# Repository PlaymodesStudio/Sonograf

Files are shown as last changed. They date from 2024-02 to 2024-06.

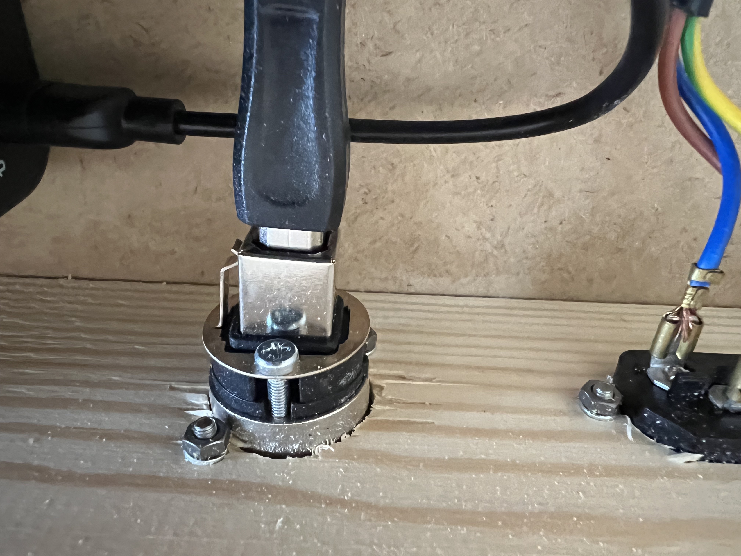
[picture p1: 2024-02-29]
PHOTOS/USB_wiring.jpg

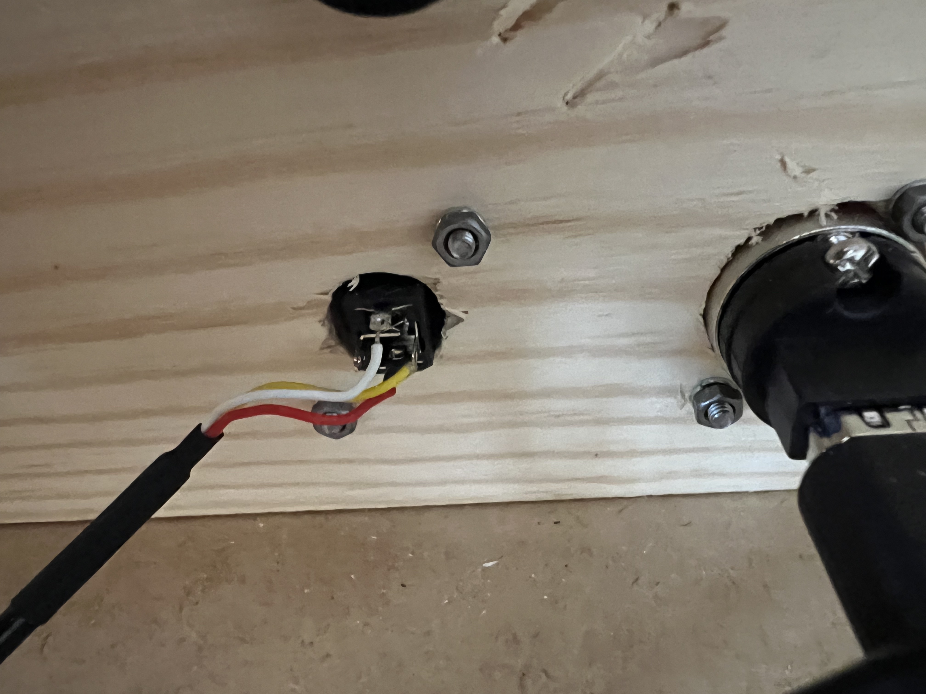
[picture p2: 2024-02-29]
PHOTOS/minijack_wiring.jpg

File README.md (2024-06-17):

SONÒGRAF DIY MATERIALS
https://www.playmodes.com/home/sonograf/

Sonògraf © 2022 by Playmodes Studio is licensed under Attribution-NonCommercial-ShareAlike 4.0 International 

final_setup

This is a compilation of software, materials list, 3d print files, CNC designs and instructions for you to build your own Sonògraf.

Please be aware that the software (a Raspberry PI 4 image file) is complete and fully working, as this constitutes the fundamental element of the Sonògraf instrument.
The source codes for the software components are provided, if you feel brave enough to analyze, make sense of the package and make your custom modifications.

Please find the software elements of the Sonògraf, including a release featuring a ready-to-burn Raspberry Pi .img file here: https://github.com/PlaymodesStudio/Sonograf_Software

(please note that we provide 2 different images: a shrinked one, hosted in github, and a complete one, hosted in Dropbox. Some people has had errors with the shrinked image, so we recommend to go directly to the full .img with the dropbox link)

The 3D prints and CNC files are provided as a mere starting point for your own project, and shouldn’t be taken as fabrication-ready:

-Some of the material listed elements can be discontinued (specific products out of stock or not being fabricated anymore)

-The 3D printing and CNC files are provided in a variety of formats (svg, ai, stl…) and you must carefully check that the designs match your materials.

-Some assembly images can give you a reference on how we did it. But, again, this can be useful or not depending on your specific design and materials availability.

-You will need some level of understanding on basic electronics (ie: wire a knob or button to an rpi adc), and be patient enough to guess how to put everything together at the hardware and software level.

-Some extra designs are provided: logotypes, pieces for collage composition…

-As of June 2024, Filippo Centenari (https://www.filippocentenari.it/) has graciously contributed with a step-by-step assembly guide. It is a very well documented PDF with all the needed stepes to follow for the set-up of a Sonògraf. Thank you Filippo!

-A user manual and educational guide is also provided, in spanish and catalan. Sorry, no english translation yet! (If you want to contribute with an English translation of the educational guide, or with a new one with your own experience, in english, this will be a highly appreciated contribution!)

Although we can’t provide personal support or guidance for possible problems with this package, we always welcome feedback and we are eager to know if you succesfully built your own version of the Sonògraf.

Please let us know your experience at info@playmodes.com

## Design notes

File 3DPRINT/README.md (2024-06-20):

3DPRINT FOLDER
Files Description

LED_Support.stl
a 3d printer ready file, with the design of the brackets that hold the LED bar

Paper_6mm_support.stl
a 3d printer ready file, with the design of the brackets that hold the A4 paper

Webcam_base.stl
a 3d printer ready file, with the design of the base to be fixed to the inner part of the wood case cover

Webcam_joint.stl
a 3d printer ready file, with the design of the joint to be fixed directly to the webcam

Webcam_support.stl
a 3d printer ready file, with the design of the support to be placed between the base and the joint

Hinge.stl
The hinge design to hold the cover of the box

Icon-set.stl
The set of icons for the physical controls, just in case you preffer to glue 3d prints instead of laser engraving these

neutrik-jack.stl
A cover for the neutrik jack connector

USB-B Neutrik-inner-support.stl
A cover for the USB connector

LOGO v1.stl
A 3D print version of the logotype, if you preffer 3D print instead of CNC

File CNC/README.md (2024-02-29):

CNC FOLDER
Files Description

Board_cut.ai
a CNC design for cutting a plywood board, adapted to the size and needs of the case listed on the materials list. It includes holes for the buttons and knobs.
If you are using a different case, buttons, or knobs, this design might not be valid for you.
In any case, please carefully check the dimensions before printing!

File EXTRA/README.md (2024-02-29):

EXTRA FOLDER
Files Description

Logotype_cut.svg
The needed pieces to put together the sonograf logotype at the cover of the case

pieces_cut.ai
Some designs for pre-made tokens which can be used as elements of a composition when playing with the Sonògraf

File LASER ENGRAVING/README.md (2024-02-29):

LASER ENGRAVING FOLDER
Files Description

board_engraving.svg
Icons and marks to be engraved on the board. This design should match the board cut pattern in the cnc folder, but please review carefully before proceeding.

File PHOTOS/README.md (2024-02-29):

PHOTOS FOLDER
Files Description

board_hole.jpg
A detail on how the side hole on the CNCed board is used to make the camera and LED bar cables pass by towards the inner side of the instrument

board.jpg
A view of the fully assembled board

board_rear.jpg
A view of the board on its rear part, with the buttons and knobs wired to the adc shield of the RPI4

button_wiring.jpg
A detail on the button wiring on the rear side of the board

camera_base.jpg
A detail of the camera base, screwed to the cover

camera_joint.jpg
A detail of the camera joint, assembled to the other parts

camera_match.jpg
A detail of the matching parts of the camera support

camera_support.jpg
A detail of the whole camera 3d printed support, in standby position

case_cover.jpg
A detail of the case cover. Pay attention to the screws that fix the camera base and the CNCed logotype.

case_hinge.jpg
A detail of the case 3d printed hinge

diagram.png
A diagram showing all the visible parts of the instrument

final_setup.jpg
A final setup example, with speakers and videoprojector

general_view_inner.jpg
A view of the inner part of the instrument, showing the RPI4 and the different wiring and power elements

general_view.jpg
A general view of the visible parts of the instrument once assembled

HDMI.jpg
A detail of the HDMI connector on the inner side

IEC_wiring.jpg
A detail of the IEC connector, on the inner side.

inner_view.jpg
A view of the inner part of the instrument, showing the RPI4 and the different wiring and power elements

knob_wiring.jpg
A detail on the button wiring on the rear side of the board

latch1.jpg
A detail on the latch parts screwed to the case

latch2.jpg
A detail on the latch parts screwed to the case

LED_support.jpg
A detail of the 3d printed LED support

minijack_wiring.jpg
A detail of the minijack connector, on the inner side.

RPI_adc.jpg
A detail view of the ADC shield for the RPI4

rpi_connections.jpg
A detail view of the different connections to the RPI conenctors. Please note that the ethernet connection/wire is not needed

USB_wiring.jpg
A detail of the USB connector, on the inner side.

using_pieces.jpg
An example image of the sonograf being used with the CNC pieces for collage compositions

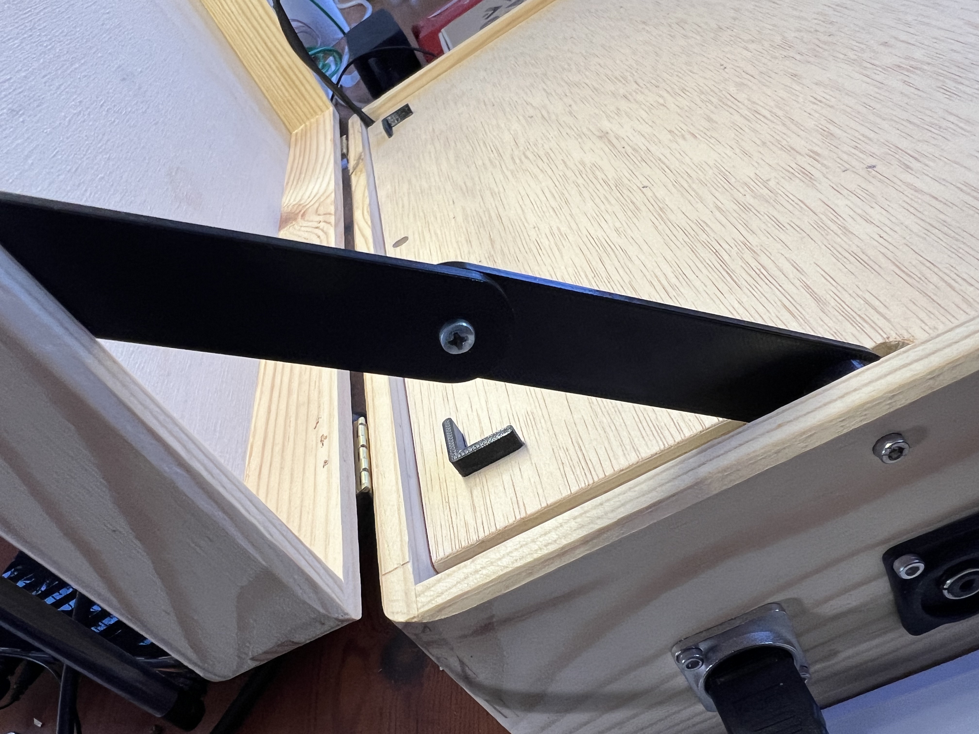
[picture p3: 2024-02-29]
PHOTOS/case_hinge.jpg

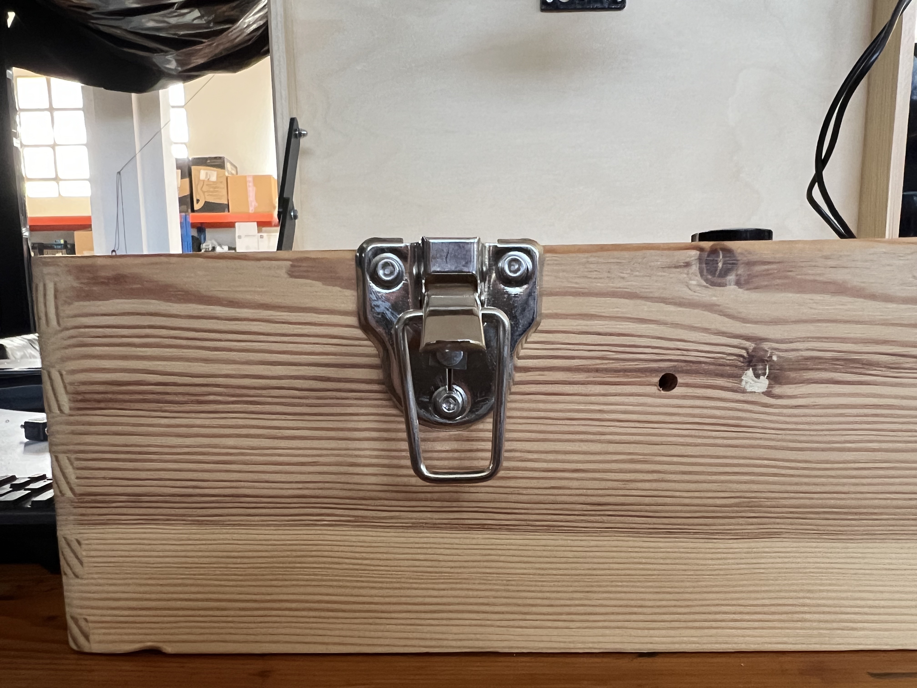
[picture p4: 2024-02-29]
PHOTOS/latch2.jpg

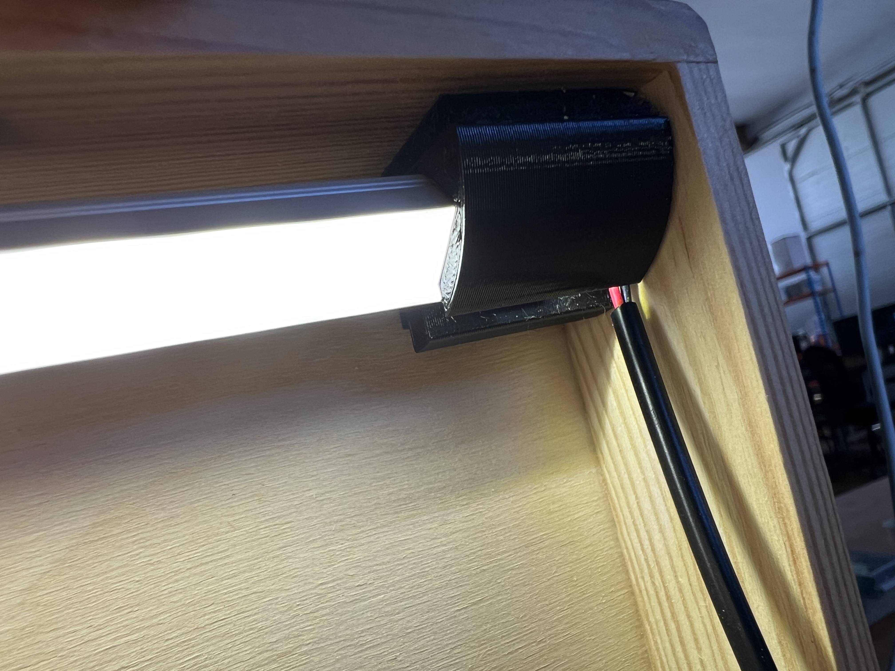
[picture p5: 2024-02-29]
PHOTOS/LED_support.jpg

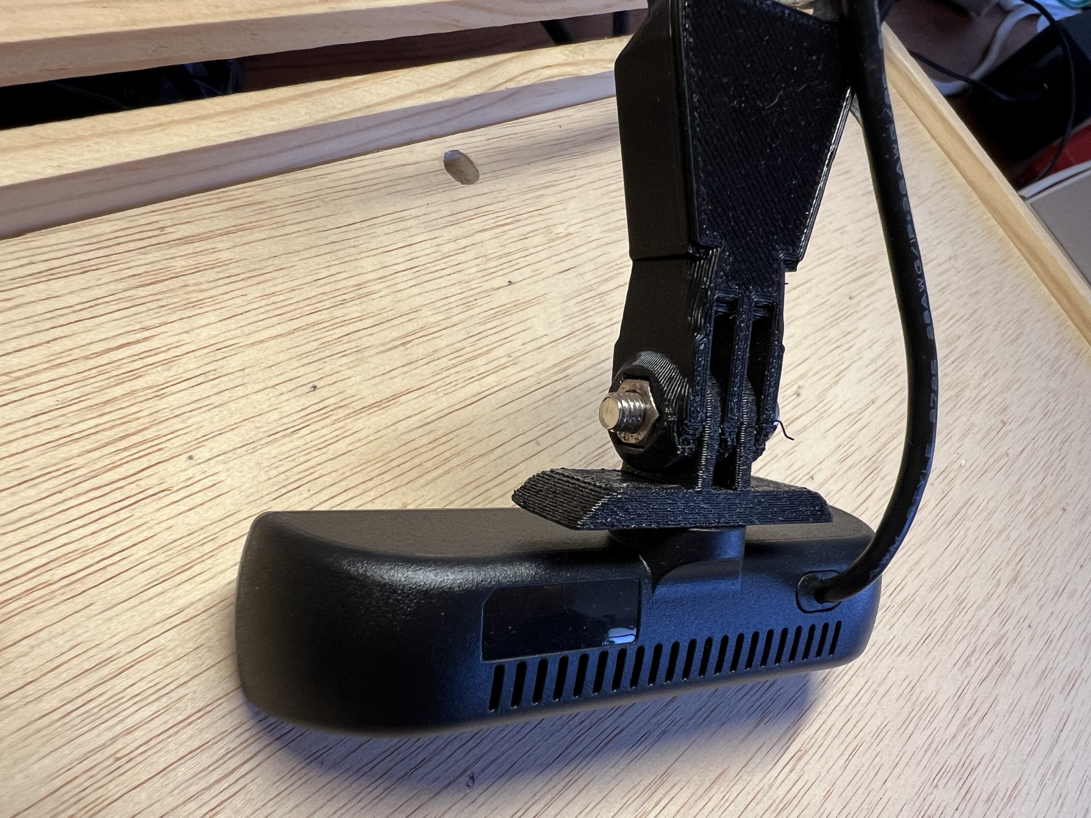
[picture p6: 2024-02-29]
PHOTOS/camera_joint.jpg

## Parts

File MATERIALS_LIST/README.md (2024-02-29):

SONÒGRAF MATERIALS LIST

On this list you will find the needed materials for a full assembly of the Sonògraf, together with its approximate price and a reference link to the material.

Please be aware that some of the materials on this list can be discontinued or out of stock, the links broken, etc.

You can probably work with other replacement parts, or make a full redesign of the Sonògraf hardware while just keeping the software.

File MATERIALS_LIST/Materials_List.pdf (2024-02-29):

Units | Unit Price (€) | Subtotal (€)
Kit RaspberryPI 4 (RPI + SD + HDMI) | 1 | 100,00 € | 100,00 € | https://www.kubii.com/en/nano-computers/3011-starter-kit-raspberry-pi4-4gb-3272496302112.html Multi power plug with USB | 1 | 14,00 € | 14,00 € | https://www.amazon.es/JSVER-pararrayos-Protectores-sobretensiones-Smartphone/dp/B07JMVSJHV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
Neutrik USB female connector | 1 | 7,14 € | 7,14 € | https://www.amazon.es/gp/product/B003L79T06/ref=ppx_yo_dt_b_asin_title_o01_s00?ie=UTF8&psc=1
Neutrik HDMI female connector | 2 | 8,00 € | 16,00 € | https://www.amazon.es/Neutrik-NAHDMI-W-Conector-Plata-25-85/dp/B004E88DMG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
USB soundcard for RPI4 | 1 | 6,50 € | 6,50 € | https://www.amazon.es/gp/product/B07S4LJ28C/ref=ppx_yo_dt_b_asin_title_o07_s00?ie=UTF8&psc=1
Aukey fullHD USB Webcam | 1 | 32,00 € | 32,00 € | https://www.pccomponentes.com/aukey-webcam-fullhd-usb
IEC Connector | 1 | 1,00 € | 1,00 € | https://www.tme.eu/es/details/cs-033/conectores-iec-60320/
IEC soldering terminals | 3 | 0,10 € | 0,30 € | https://www.tme.eu/es/details/2670.05.00.9/conectores-no-aislados/imp/
Potentiometers 10kohm | 4 | 2,00 € | 8,00 € | https://www.tme.eu/es/details/r16148-1a-2-b10k/potenciometros-de-carbono-de-una-revol/sr-passives/
Potentiometer Caps | 4 | 3,00 € | 12,00 € | https://www.tme.eu/es/details/gf6m-25x15-c/perillas-para-potenciometros-axiales/sr-passives/
25cm minijack wire | 1 | 2,24 € | 2,24 € | https://cablematic.com/es/productos/cable-audio-stereo-minijack-35-mm-20cm-TV077/?cr=EUR&ct=ES Minijack Female connector | 1 | 3,65 € | 3,65 € | https://www.amazon.es/gp/product/B073QW1RB2/ref=ppx_yo_dt_b_asin_title_o00_s00?ie=UTF8&psc=1
USB wire 25cm | 1 | 0,75 € | 0,75 € | https://cablematic.com/ca/productes/cable-usb-20-ab-mascle-blanc-20cm-UR031/
LED bar | 1 | 8,36 € | 8,36 € | https://www.amazon.es/gp/product/B08GLRYYX2/ref=ppx_yo_dt_b_asin_title_o05_s00?ie=UTF8&psc=1
Placa rpi amb adc | 1 | 9,73 € | 16,73 € | https://es.rs-online.com/web/p/products/1887099/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
Toggle button | 1 | 1,80 € | 1,80 € | https://www.tme.eu/es/details/v12f-11-b/interruptores-estandar/onpow/las2f-11-b/
Switch buttons | 3 | 1,80 € | 5,40 € | https://www.tme.eu/es/details/v12f-11-r/interruptores-estandar/onpow/las2f-11-r/ Wood case | 1 | 24,95 € | 24,95 € | https://www.amazon.es/gp/product/B079287L4W/ref=ppx_yo_dt_b_asin_title_o03_s00?ie=UTF8&psc=1 Metal toggle latch | 2 | 1,38 € | 2,75 € | https://www.amazon.es/gp/product/B08DLKGFJL/ref=ppx_yo_dt_b_asin_title_o00_s00?ie=UTF8&psc=1
Case handle | 1 | 3,50 € | 3,50 € | https://www.amazon.es/gp/product/B098MH3695/ref=ppx_yo_dt_b_asin_title_o00_s00?ie=UTF8&psc=1
Plywood piece 40x30x1cm | 1 | 7,00 € | 7,00 € | https://www.amazon.es/Chely-Intermarket-contrachapado-Especial-Pirograbado/dp/B07RK4T9SW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
IEC wire | 1 | 5,00 € | 5,00 € | https://www.amazon.es/PremiumCord-Cable-alimentaci%C3%B3n-protecci%C3%B3n-Contacto/dp/B07NSM66DZ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 Wood bolts | 4 | 0,50 € | 2,00 €
Total Approximate Price | 281,07 €

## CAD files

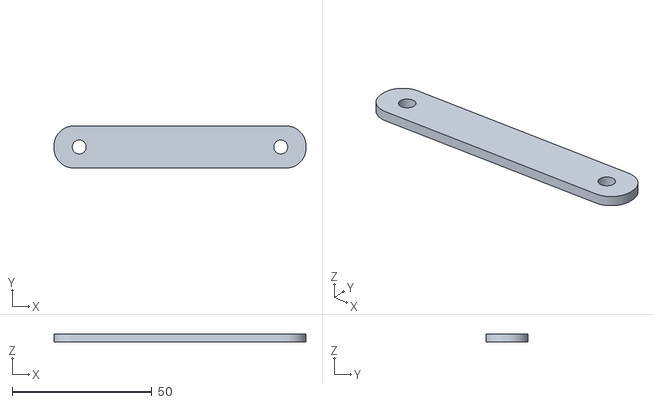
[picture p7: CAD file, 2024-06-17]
3DPRINT/hinge.stl
90.0 x 15.0 x 3.00

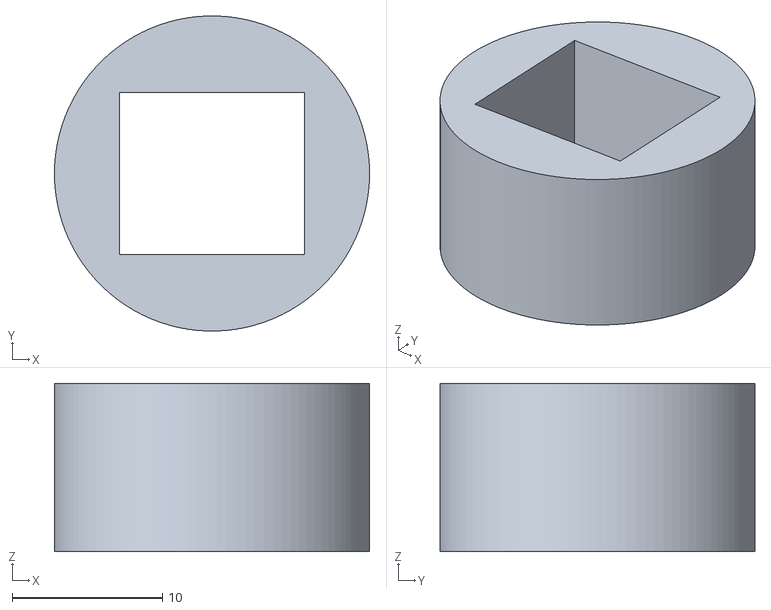
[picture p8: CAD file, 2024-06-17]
3DPRINT/USB-B Neutrik-inner-support.stl
21.0 x 21.0 x 11.2

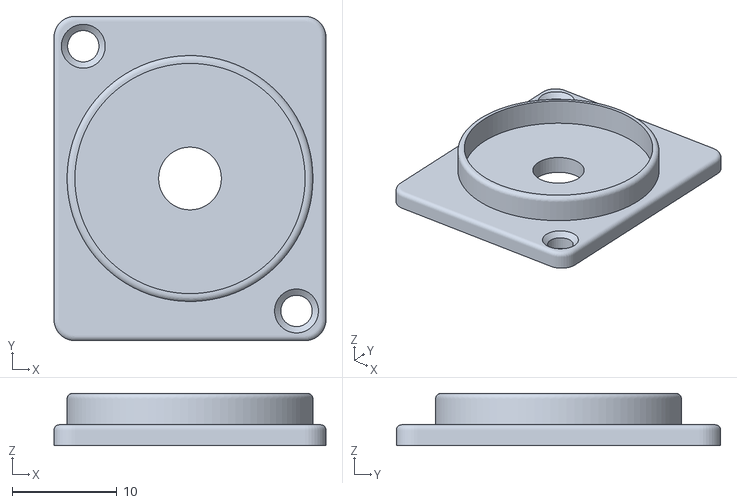
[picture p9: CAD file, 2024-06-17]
3DPRINT/neutrik-jack.stl
26.0 x 31.0 x 5.00

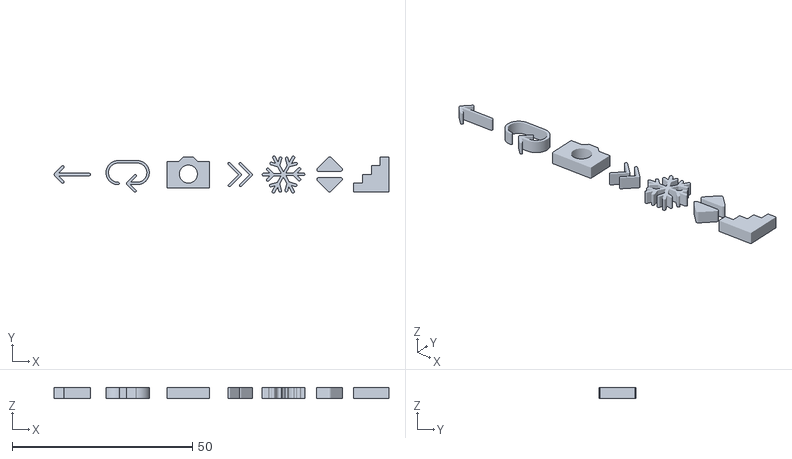
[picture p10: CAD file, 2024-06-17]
3DPRINT/icon-set.stl
92.9 x 10.3 x 3.00

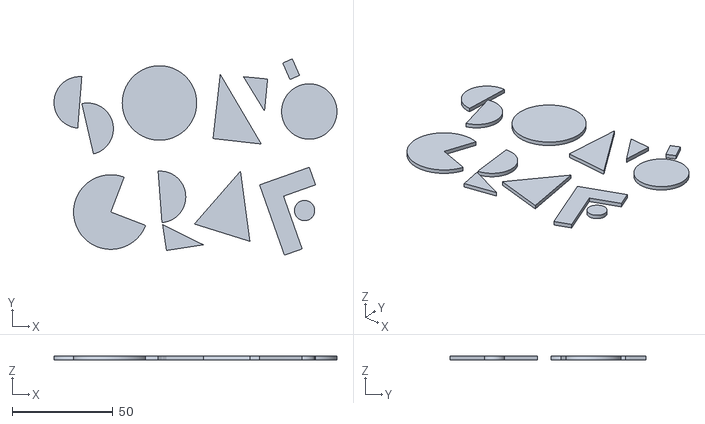
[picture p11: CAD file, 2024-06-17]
3DPRINT/LOGO v1.stl
140.5 x 97.5 x 2.00

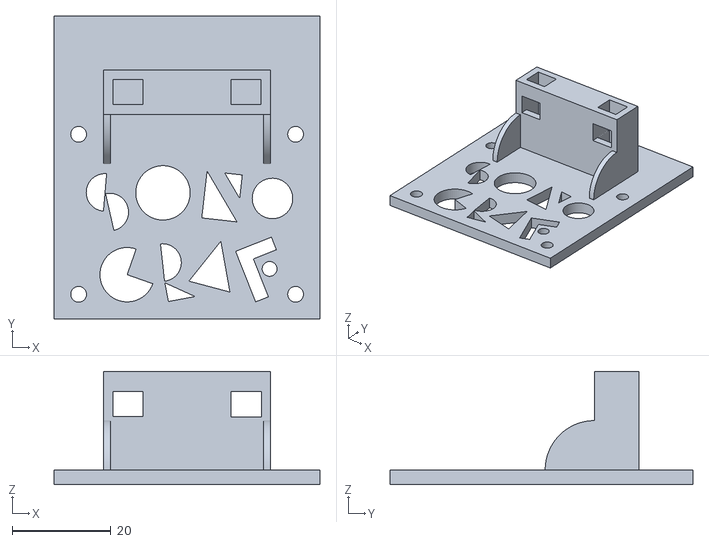
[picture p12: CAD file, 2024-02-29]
3DPRINT/webcam_base.stl
54.0 x 61.5 x 23.0

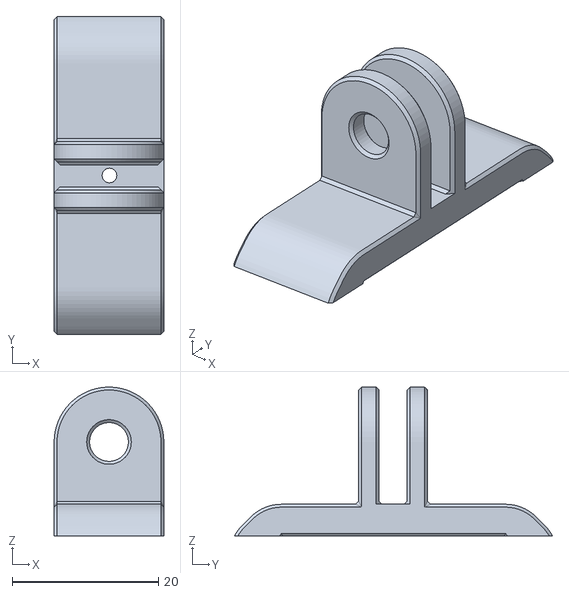
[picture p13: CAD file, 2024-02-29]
3DPRINT/webcam_joint.stl
15.0 x 43.4 x 20.3

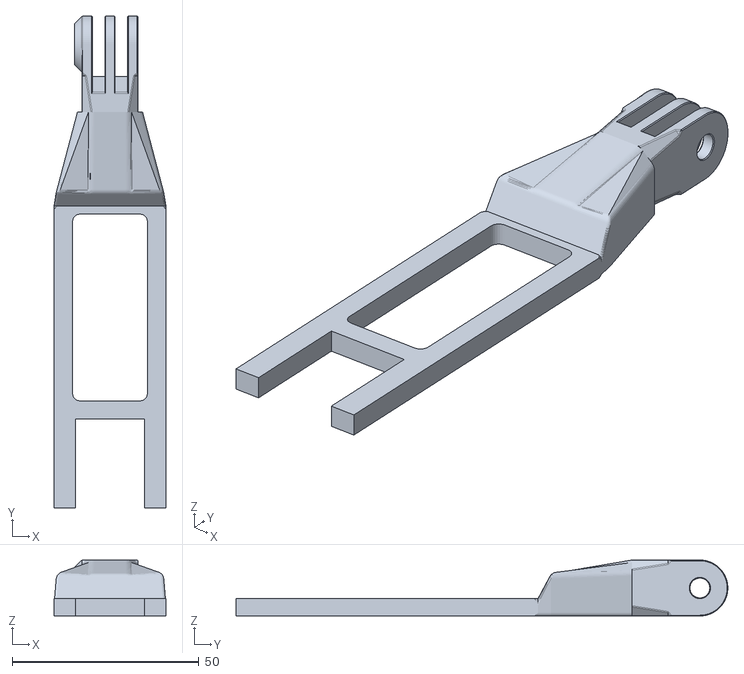
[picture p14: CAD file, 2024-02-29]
3DPRINT/webcam_support.stl
30.0 x 131.7 x 15.0

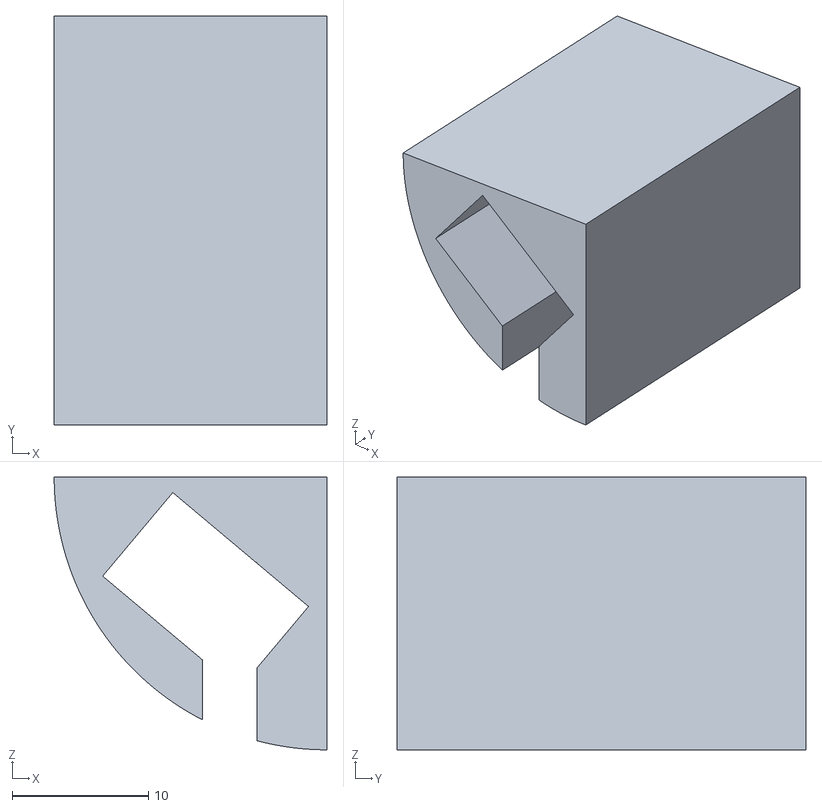
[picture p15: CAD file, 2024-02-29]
3DPRINT/LED_support.stl
20.0 x 30.0 x 20.0

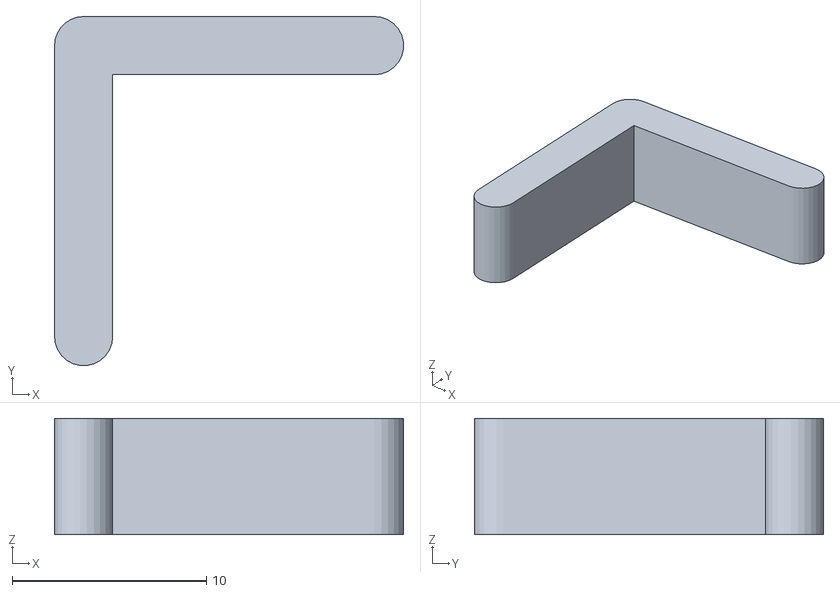
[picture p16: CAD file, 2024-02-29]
3DPRINT/paper_6mm_support.stl
18.0 x 18.0 x 6.00

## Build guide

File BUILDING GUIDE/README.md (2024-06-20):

BUILDING GUIDE

This is a step-by-step guide to assist you on building your own Sonògraf, based on the materials list we provide.
It will give as a result an "exact" clone of the unit we designed, but of course, you can add your own upgrades and improvements to the unit!

This building guide has been carefully crafted and contributed by Filippo Centenari (https://www.filippocentenari.it/)

If you make a cool upgrade to the unit, and you are able to provide an alternative building guide (a video tutorial would be amazing!), we're open to receive and publish your contribution!

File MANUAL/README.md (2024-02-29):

MANUAL FOLDER
Files Description

sonograf_cat.pdf
sonograf_es.pdf
Catalan and Spanish versions of the educational guide.
Sorry, no english version at the moment!

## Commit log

2024-02-29 added materials list
2024-06-07 added a schemw for wiring
2024-06-17 added missing stl by Filippo Centenari
    [LOGO v1.stl, USB-B Neutrik-inner-support.stl, hinge.stl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]
